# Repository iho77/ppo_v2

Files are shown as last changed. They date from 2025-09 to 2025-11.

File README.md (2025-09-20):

Shield: [][cc-by-nc]

This work is licensed under a
[Creative Commons Attribution-NonCommercial 4.0 International License][cc-by-nc].

[][cc-by-nc]

[cc-by-nc]: https://creativecommons.org/licenses/by-nc/4.0/
[cc-by-nc-image]: https://licensebuttons.net/l/by-nc/4.0/88x31.png
[cc-by-nc-shield]: https://img.shields.io/badge/License-CC%20BY--NC%204.0-lightgrey.svg

# PPO2 Display

A high-precision Partial Pressure of Oxygen (PPO2) monitoring system for technical diving, built on ESP32-C3 with dual O2 sensor support and advanced signal processing algorithms.

## Safety Notes

⚠️ **WARNING**:

OXYGEN PPO MONITORING SOFTWARE

This software is not a dive computer, life-support system, medical device, or safety-critical instrument. It is provided for informational and educational purposes only. Readings may be inaccurate, delayed, or fail due to sensor drift/aging, moisture, calibration error, power or hardware faults, electromagnetic interference, or software bugs.

Do not rely on this software to determine breathing-gas safety. Always follow certified dive training and procedures, use approved equipment, carry independent/redundant instruments, and maintain conservative dive plans. Diving—especially with rebreathers—carries inherent risks of serious injury or death.

The software is provided “AS IS,” without warranties of any kind. To the maximum extent permitted by law, the developer disclaims all liability for any loss, damage, injury, or death arising from use or misuse of this software. By downloading, installing, or using the software, you acknowledge and accept all risks and agree to release, indemnify, and hold the developer harmless from any claims.

If you do not agree, do not use this software.

⚠️ **IMPORTANT**: This sostware developed  using Anthropic Claude heavly with lack of human verification and testing.  

⚠️ **IMPORTANT**: This system is designed for TESTING PURPUSES ONLY. Users must:

1. **Validate Calibration**: Always verify calibration with known gas mixtures
2. **Dual Sensor Monitoring**: Never dive with single sensor operation
3. **Regular Maintenance**: Check sensor health and calibration frequently
4. **Backup Systems**: Always carry independent PPO2 monitoring
5. **Training Required**: Proper technical diving certification essential

This system is a diving aid and should not be the sole method of gas monitoring during technical dives.

## Required Tools & Environment

  - ESP-IDF Framework - Espressif's official development framework
  - CMake (3.16+) - Build system
  - Python - For ESP-IDF tools and flashing
  - Git - For version control and ESP-IDF installation

## Hardware Platform

  - Target MCU: ESP32-C3 Development Board
  - Display: 128x128 SH1107 OLED (I2C at 0x3D, 400kHz)
  - Sensors: Internal ADC for O2 sensor readings
  - Buttons: 2x GPIO buttons (MODE/SELECT)
  - LED: Built-in RGB LED for warnings

## Key Libraries & Components

  - FreeRTOS - Real-time operating system (1kHz tick)
  - ESP-IDF I2C Master Driver - Hardware communication
  - NVS Flash - Non-volatile storage for configuration
  - ESP Task Watchdog - System safety monitoring
  - Custom Components:
    - Display Manager (SH1107 driver)
    - Sensor Manager (O2 sensor interface)
    - Button Manager (GPIO with debouncing)
    - Warning Manager (LED control)
    - PPO2 Logger (data logging)

### Pin Configuration
```
GPIO 0  -> ADC1_CH0 (O2 Sensor 1)
GPIO 1  -> ADC1_CH1 (O2 Sensor 2) 
GPIO 3  -> ADC1_CH3 (Battery voltage divider 1/3)
GPIO 6  -> I2C SDA (Display)
GPIO 7  -> I2C SCL (Display)
GPIO 5  -> MODE Button
GPIO 10  -> SELECT Button
GPIO 8  -> RGB LED (Warning system)
```

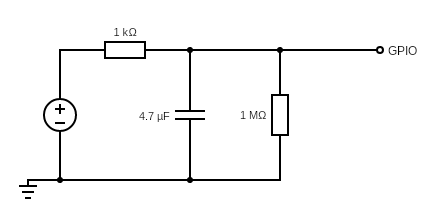
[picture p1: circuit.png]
scheme


## Key Features

### Sensor Management
- **Dual O2 Sensor Support**: Independent sensor processing with disagreement detection
- **Single sensor auto detection**: Short  Sensor + in cable connector to ground - device starts to work in 1 sensor modeI
- **Multipoint Calibration System**: Air (21%), O2 (100%) or custom mix calibration points
- **Advanced Signal Processing**: Median-of-5 → EMA → Slew-rate limiting pipeline
- **Sensor Health Monitoring**: Automatic failure detection and recovery
- **Battery Monitoring**: Real-time voltage and percentage display

### Display System
- **Main Display**: Large PPO2 values with calibration status indicators
- **Warning System**: Scrolling text warnings with LED color coding
- **Battery Display**: Dynamic battery icon with voltage readout
- **Menu System**: Clean navigation with visual selection indicators

### Warning System
- **PPO2 Thresholds**: Configurable low/high warning and alarm levels
- **Sensor Disagreement**: Automatic detection of sensor variance
- **Visual Alerts**: Color-coded LED (Green/Yellow/Red) with blinking patterns
- **Display Integration**: Warning messages shown on main screen

## Core Algorithms

### 1. Robust Signal Processing Pipeline

The system implements a sophisticated 3-stage filtering pipeline for each O2 sensor:

Use 3 stages: spike removal → low-pass → rate limit + debounced alarms.

Spike/outlier killer (median-of-5)
At each 20 Hz step, keep the last 5 raw samples and take the median.

Purpose: remove single-sample glitches without adding much lag (~0.1–0.15 s).

Exponential moving average (EMA) with ~5 s time constant
Let y[n] = y[n−1] + α (x_med[n] − y[n−1]), where x_med is from step 1.

Sampling period dt = 1/20 = 0.05 s.

Choose time constant τ ≈ 5 s → α = dt/τ = 0.05/5 = 0.01.

Why: 5 s LPF kills high-freq jitter while keeping latency modest (~τ behind fast ramps).

Slew-rate limiter (enforce physics)
If the environment cannot change by more than Δ_meaningful per 10 s, set

S_max = Δ_meaningful / 10 (units per second).

Per-sample limit: Δ_per_sample = S_max * dt.
Then clamp the EMA output change:
y_lim[n] = clamp(y[n−1] − Δ_per_sample, y[n], y[n−1] + Δ_per_sample).

Purpose: guarantees your displayed value can’t “move” faster than reality.

Debounced, hysteretic warnings (no flicker)

Trigger threshold: T_hi. Clear threshold: T_lo (with T_lo closer to normal than T_hi → hysteresis gap).

Require persistence: only raise a warning if y_lim[n] > T_hi continuously for T_confirm (e.g., 2–3 s).

Only clear if y_lim[n] < T_lo continuously for T_clear (e.g., 2–3 s).

Implement with two counters that increment while condition holds and reset otherwise.

That stack is O(1) memory and CPU, super stable, and easy to tune.

### 2. Multipoint Calibration System

Replaces traditional linear calibration with a robust 1 or 2-point system:

#### Calibration Points
1. **Air Calibration** (21% O2 at 1 bar): `PPO2 = 0.21 bar`
2. **Oxygen Calibration** (100% O2 at 1 bar): `PPO2 = 1.00 bar`
2. **Custom mix Calibration** (Custom % O2 at 1 bar)

System can works with 1 point calibration or 2 points calibration. In case of 1 point calibration second point is 0 mv\ 0% oxygen.

### 3. Sensor Health Monitoring

#### Health Checks
1. **Voltage Range Validation**: 0-1000mV acceptable range
2. **Calibration Validity**: Both sensors must have valid calibration
3. **Sensor Disagreement**: PPO2 difference > 0.05 bar triggers warning
4. **Communication Errors**: ADC read failures tracked and recovered

# Calibration-Based Drift & Linearity Tracking (Strategy 1)

A clear, hands-on guide you can mirror in logs, a spreadsheet, or firmware notes.

## What you track (per sensor)

* **Gain / sensitivity `k`** (mV/ata): millivolts per 1.0 ata ppO₂.
* **Offset `b`** (mV): reading at ppO₂ = 0 (should be near 0).
* **Normalized sensitivity `S = k / k₀`** vs **new-sensor baseline** `k₀`.
* **Linearity** across multiple known ppO₂ points: **`R²`** and **max residual** (mV).
* **Drift rate** (e.g., %/month) and **predicted EOL** date (when `S` hits your fail threshold, e.g., `0.70`).

---

## Two-Point Calibration (minimum viable)

At each calibration, expose the sensor to two **known** ppO₂ points and record:

* `(p₁, m₁)`: e.g., **air at surface** → `p₁ ≈ 0.209` ata, measured `m₁` (mV)
* `(p₂, m₂)`: e.g., **100% O₂ at surface** → `p₂ = 1.00` ata, measured `m₂` (mV)

Fit a line `m = k·p + b`:

```
k = (m₂ − m₁) / (p₂ − p₁)
b = m₁ − k · p₁
```

Then compute **normalized sensitivity**:

```
S = k / k₀
```

Where `k₀` is your **new-sensor baseline** (mV/ata).

---

## Worked Example A — two-point checks over time (one sensor)

Assume `k₀ = 52.0` mV/ata (≈ 11 mV in air, ≈ 52 mV at 1.0 ata O₂).

| Date | Air mV `m₁` | O₂ mV `m₂` | Estimated `k` (mV/ata) | `b` (mV) | `S = k/k₀` |
| --- | ---: | ---: | ---: | ---: | ---: |
| 2025-01-01 | 10.99 | 52.25 | 52.16 | 0.09 | 1.003 |
| 2025-05-01 | 10.45 | 49.51 | 49.37 | 0.14 | 0.950 |
| 2025-10-01 | 9.48 | 45.86 | 46.00 | −0.14 | 0.885 |
| 2026-03-01 | 8.18 | 39.82 | 39.99 | −0.18 | 0.769 |

### Interpretation

* Sensitivity `S` drifts from \~1.00 → 0.77 over \~14 months (≈ 1.6 %/month).
* **Caution** when `S < 0.80` (here: 2026-03-01).
* **Predict EOL** when `S` hits **0.70**: extrapolation from the last trend ≈ **Aug 2026** (\~19 months from first calibration).

**Log each time:** the two mV readings and the computed `k`, `b`, `S`, plus a trendline of `S` vs time (and ETA to `S = 0.70`).

---

## Practical guardrails

* If `|b| > 2–3` mV or it drifts steadily, investigate (zero-current leakage, moisture, wiring).
* If degradation accelerates (> \~3–5 %/month), plan an early swap.

#### Failure Recovery
- **Graceful Degradation**: System continues with single sensor
- **Fail-Safe PPO2**: Conservative 0.21 bar default during total failure
- **Automatic Recovery**: Sensors re-validated on successful reads

### 4. Warning State Machine

#### Warning States
```c
typedef enum {
    WARNING_STATE_NORMAL = 0,    // Green LED - PPO2 in range
    WARNING_STATE_WARNING,       // Yellow blinking - PPO2 at limits  
    WARNING_STATE_ALARM         // Red blinking - PPO2 dangerous
} warning_state_t;
```

#### PPO2 Thresholds (Configurable)
- **Low Warning**: 0.19 bar (hypoxia risk)
- **Low Alarm**: 0.18 bar (severe hypoxia)
- **High Warning**: 1.4 bar (oxygen toxicity risk)
- **High Alarm**: 1.6 bar (severe toxicity risk)

#### LED Patterns
- **Normal**: Solid green
- **Warning**: Yellow blink at 2Hz (250ms on/off)
- **Alarm**: Red blink at 4Hz (125ms on/off)

## System Architecture

### Component Organization
```
├── main/                   # Main application and mode management
│   ├── main.c             # System initialization and 20Hz main loop
│   └── modes/             # Mode-specific implementations
├── components/
│   ├── app_common/        # Shared types and configuration
│   ├── sensor_manager/    # O2 sensor processing and calibration
│   ├── display_manager/   # LVGL display driver and UI
│   ├── warning_manager/   # LED warning system
│   ├── button_manager/    # GPIO button handling
│   └── sh1107_driver/     # Low-level display driver
```

### Data Flow
```
Sensors (20Hz) → Filtering → Calibration → Warning Analysis → Display Update
                     ↓
              Health Monitoring → Recovery Actions
```

## Menu System

### Main Menu Items
1. **Sensor Calibration** - Dual sensor calibration with gas selection
2. **Reset Calibration** - Individual or bulk calibration reset
3. **Print Logs** - Debug output to serial console
4. **Sensor Health** - Real-time sensor diagnostics
5. **System Setup** - Configuration and thresholds
6. **Power Off** - System shutdown

### Calibration Workflow
1. **Gas Selection**: Air, O2, or Custom (configurable %)
2. **Dual Sensor Display**: Live mV readings for both sensors
3. **Calibration Action**: Simultaneous calibration of both sensors
4. **Validation**: Automatic sanity checks and confirmation

### Setup Options
- **PPO2 Thresholds**: Warning and alarm levels for low/high PPO2
- **Display Settings**: Brightness and contrast
- **Sensor Configuration**: Individual sensor enable/disable
- **System Parameters**: Sample rates and filter constants

## Technical Specifications

### Performance
- **Update Rate**: 20 Hz sensor sampling and display refresh
- **Response Time**: ~5 seconds (90% settling due to EMA filtering)
- **Accuracy**: ±0.01 bar PPO2 (post-calibration)
- **Resolution**: 12-bit ADC (0.25mV resolution)

## Contributing

Contributions welcome! Please read CONTRIBUTING.md for guidelines on:
- Code style and standards
- Testing requirements
- Safety considerations for diving equipment

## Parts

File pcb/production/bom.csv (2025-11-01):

Designator | Footprint | Quantity | Value | LCSC Part #
BT1 | JST_XH_B2B-XH-A_1x02_P2.50mm_Vertical | 1 | Battery | C7429632
C1, C2 | 0805 | 2 | 1uF | C24123
C3 | 0805 | 1 | 4.7uF | C107365
C4, C5 | 0805 | 2 | 10uF | C1713
J1, J2 | JST_XH_B2B-XH-A_1x02_P2.50mm_Vertical | 2 | Conn_01x02_Socket | C7429632
J3 | JST_XH_B4B-XH-AM_1x04_P2.50mm_Vertical | 1 | Conn_01x04_Socket
L1 | 0402 | 1 | 1.5uH | C6364721
R1, R2 | 0805 | 2 | 10K | C17414
R3 | 0805 | 1 | 200k | C149504
R4 | 0805 | 1 | 100K | C2907238
U3 | WSON-10-1EP_2.5x2.5mm_P0.5mm_EP1.2x2mm | 1 | TPS63031DSK | C15516

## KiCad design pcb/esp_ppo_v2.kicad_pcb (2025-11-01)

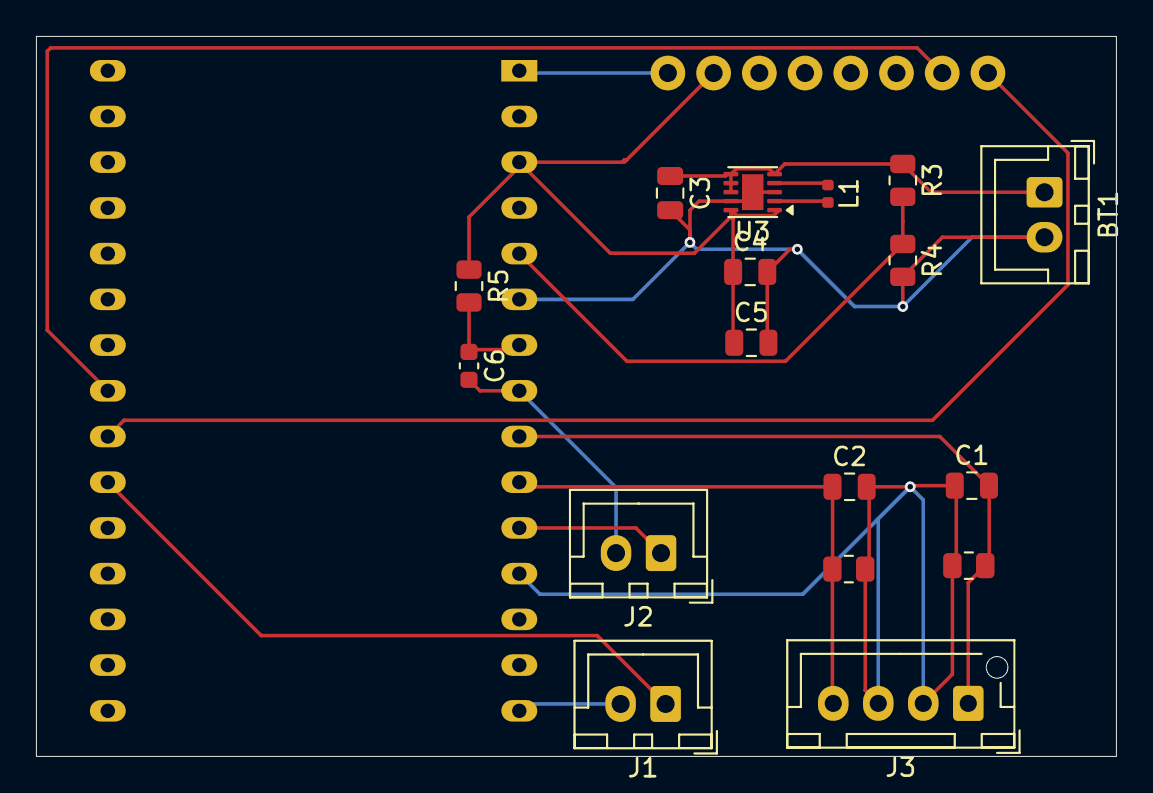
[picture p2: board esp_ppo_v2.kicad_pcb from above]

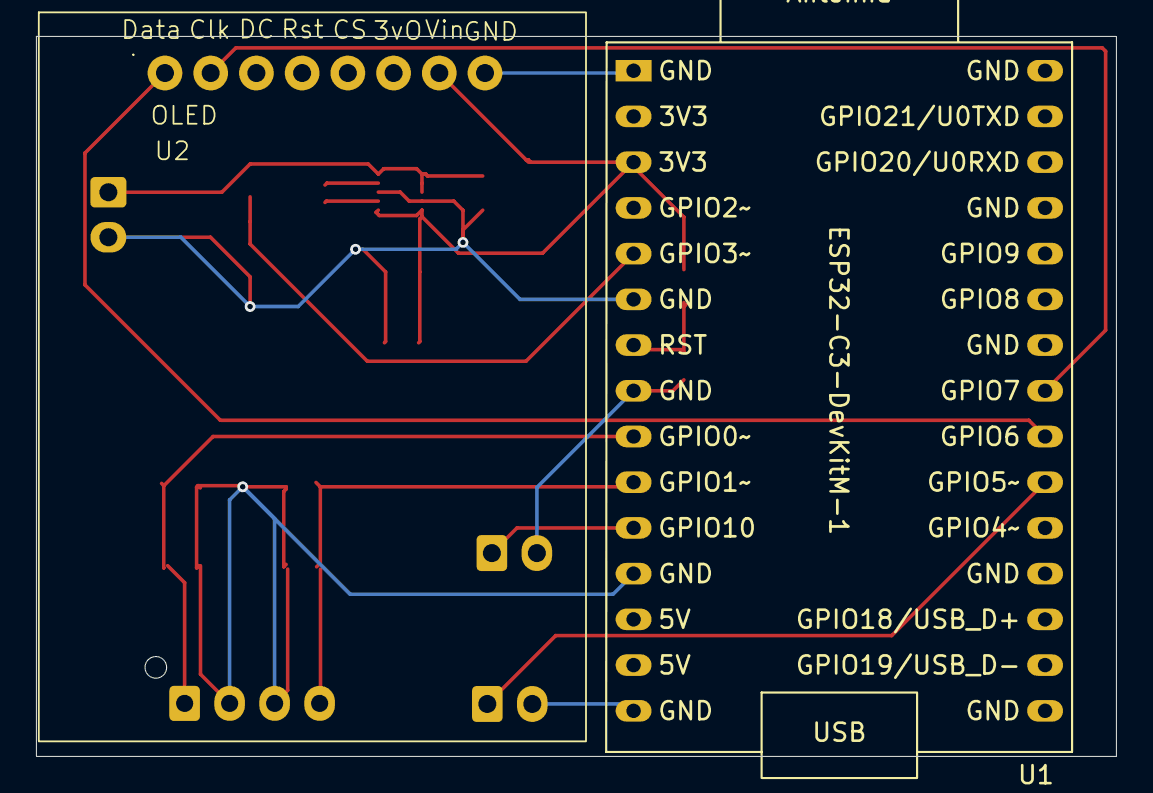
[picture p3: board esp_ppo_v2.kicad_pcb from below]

Board: 2 copper layers, 60.0 x 40.0 mm, 19 parts (2 on the bottom side), 13 nets.

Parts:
BT1: Battery; JST_XH_B2B-XH-A_1x02_P2.50mm_Vertical
C1, C2: 1uF; C_0805_2012Metric
C3: 4.7uF; C_0805_2012Metric
C4, C5: 10uF; C_0805_2012Metric
C6: 10uF; C_0603_1608Metric
J1, J2: Conn_01x02_Socket; JST_XH_B2B-XH-A_1x02_P2.50mm_Vertical
J3: Conn_01x04_Socket; JST_XH_B4B-XH-AM_1x04_P2.50mm_Vertical
L1: 1.5uH; L_0402_1005Metric
R1, R2: 10K; R_0805_2012Metric
R3: 200k; R_0805_2012Metric
R4: 100K; R_0805_2012Metric
R5: 10k; R_0805_2012Metric
U1: ESP32-C3-DevKitM-1
U2: 128x128_OLED
U3: TPS63031DSK; WSON-10-1EP_2.5x2.5mm_P0.5mm_EP1.2x2mm

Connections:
+3.3V: C4.1, C5.1, R5.1, U1.2 (3V3), U1.3 (3V3), U2.7 (Vin), U3.1 (VOUT), U3.10 (FB)
+BATT: BT1.1 (+), C3.1, R3.1, U3.5 (VIN), U3.6 (EN), U3.7 (PS/SYNC), U3.8 (VINA)
ADC_1: C2.1, J3.4, R2.1, U1.10 (GPIO1)
ADC_2: C1.2, J3.1, R1.2, U1.9 (GPIO0)
ADC_BAT: R3.2, R4.1, U1.5 (GPIO3)
BTN-M: J1.1, U1.21 (GPIO5)
BTN-S: J2.1, U1.11 (GPIO10)
GND: BT1.2 (-), C1.1, C2.2, C3.2, C4.2, C5.2, C6.2, J1.2, J2.2, J3.2, J3.3, R1.1, R2.2, R4.2, U1.1 (GND), U1.6 (GND), U1.8 (GND), U1.12 (GND), U1.15 (GND), U1.16 (GND), U1.19 (GND), U1.24 (GND), U1.27 (GND), U1.30 (GND), U2.8 (GND), U3.3 (PGND), U3.9 (GND), U3.11 (PGND)
unnamed: C6.1, R5.2, U1.7 (RST)
unnamed: L1.1, U3.4 (L1)
unnamed: L1.2, U3.2 (L2)
SCL: U1.23 (GPIO7), U2.2 (Clk)
SDA: U1.22 (GPIO6), U2.1 (Data)

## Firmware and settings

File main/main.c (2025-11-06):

/**
 * @file main.c
 * @brief PPO2 HUD main application - Simplified architecture
 */

#include "sdkconfig.h"
#include "freertos/FreeRTOS.h"
#include "freertos/task.h"
#include "esp_system.h"
#include "esp_log.h"
#include "esp_timer.h"
#include "nvs_flash.h"
#include <math.h>
#include <string.h>

// Application components
#include "button_manager.h"
#include "display_manager.h"
#include "sensor_manager.h"
#include "sensor_calibration.h"  // For sensor health enums
#include "ppo2_logger.h"          // PPO2 measurement logging
// Using internal ADC and no external sensor managers
#include "warning_manager.h"
#include "app_types.h"
#include "app_config.h"
#include "driver/i2c_master.h"
#include "esp_sleep.h"
#include "driver/gpio.h"
#include "driver/rtc_io.h"
#include "soc/rtc.h"
#include "esp_task_wdt.h"
#include "driver/usb_serial_jtag.h"

static const char *TAG = "PPO2_HUD";

// ========== HARDWARE CONFIGURATION ==========
// GPIO Pin Assignments for ESP32-C3 Development Board
#define GPIO_I2C_SDA            GPIO_NUM_6  // I2C Data line blue
#define GPIO_I2C_SCL            GPIO_NUM_7  // I2C Clock line  yellow
#define GPIO_BUTTON_MODE        GPIO_NUM_10  // Mode/menu button
#define GPIO_BUTTON_SELECT      GPIO_NUM_5  // Select/enter button
#define GPIO_WARNING_LED        GPIO_NUM_8  // Built-in RGB LED
//#define GPIO_WARNING_1LED       GPIO_NUM_12  // Not used
//#define GPIO_WARNING_2LED       GPIO_NUM_13  // Not used

// I2C bus configuration
#define I2C_BUS_SDA_PIN         GPIO_I2C_SDA
#define I2C_BUS_SCL_PIN         GPIO_I2C_SCL
#define I2C_BUS_FREQ_HZ         100000
#define I2C_BUS_PORT            I2C_NUM_0

// I2C Device addresses
// Display I2C address is handled by display_manager (uses 0x3D default for SH1107)
// Using internal ADC - no external I2C sensor addresses needed

// Warning system configuration
#define WARNING_LED_GPIO        GPIO_WARNING_LED

// Application states (simplified from complex mode system)
typedef enum {
    APP_STATE_MAIN = 0,        // Primary diving display
    APP_STATE_MENU,            // Menu overlay
    APP_STATE_CALIBRATION,     // Calibration overlay
    APP_STATE_CAL_RESET,       // Calibration reset screen
    APP_STATE_SETUP,           // Setup overlay
    APP_STATE_LOG,             // Log viewer overlay  
    APP_STATE_PRINT_CALIBRATION, // Print calibration to debug and show message
    APP_STATE_SENSOR_HEALTH,   // Print sensor health to debug and show message
    APP_STATE_SYSTEM_MESSAGE,  // System message display
    APP_STATE_MAX
} app_state_t;

// Setup mode menu items
typedef enum {
    SETUP_ITEM_WARN_LOW_PPO2 = 0,
    SETUP_ITEM_ALARM_LOW_PPO2,
    SETUP_ITEM_WARN_HIGH_PPO2,
    SETUP_ITEM_ALARM_HIGH_PPO2,
    SETUP_ITEM_SENSOR_DISAGREEMENT,
    SETUP_ITEM_ATMOSPHERIC_PRESSURE,
    SETUP_ITEM_SAVE,
    SETUP_ITEM_BACK,
    SETUP_ITEM_COUNT
} setup_item_t;

// Display update thresholds
#define PPO2_DISPLAY_UPDATE_THRESHOLD 0.02f  // Update display if PPO2 changes by >= 0.02
#define DISPLAY_MAX_STALENESS_MS      1000   // Always refresh at least once per second



// Application context
typedef struct {
    app_state_t current_state;
    app_state_t previous_state;
    uint32_t state_entry_time;
    uint8_t menu_selected_item;
    uint8_t menu_item_count;
    // Calibration mode state (dual sensor simultaneous calibration)
    float calibration_o2_percent;  // Known O2 percentage for calibration
    uint8_t calibration_menu_item;  // Current menu item being navigated
    uint8_t calibration_selected_gas; // Selected gas type for calibration (1=Air, 2=O2, 3=Custom)
    bool calibration_custom_editing; // True when editing custom percentage
    bool calibration_in_action_mode; // True when navigating calibrate/back, false when selecting gas
    bool calibration_session_active; // True if first gas has been calibrated, waiting for second gas
    float calibration_first_gas_percent; // O2 percentage of first calibrated gas
    // Setup mode state
    uint8_t setup_selected_item;   // Current setup menu item
    bool setup_editing;            // True when editing a value
    uint8_t setup_digit_index;     // Current digit being edited (0-based)
    uint8_t setup_digit_count;     // Total number of digits for current value
    app_config_t setup_temp_config; // Temporary config for editing
    // Calibration reset mode state
    uint8_t cal_reset_menu_item;   // 0=reset live, 1=reset default, 2=back
    float current_sensor0_mv;      // Current sensor 0 reading (mV)
    float current_sensor1_mv;      // Current sensor 1 reading (mV)
    // System message state
    char system_message[256];      // Current system message text
} app_context_t;

// Global application context
static app_context_t s_app_ctx = {
    .current_state = APP_STATE_MAIN,
    .previous_state = APP_STATE_MAIN,
    .menu_selected_item = 0,
    .menu_item_count = 6, // Will be updated dynamically in app_main()
    .calibration_o2_percent = O2_PERCENT_DEFAULT_AIR,
    .calibration_menu_item = 1,
    .calibration_selected_gas = 1, // Start with Air selected
    .calibration_custom_editing = false,
    .calibration_in_action_mode = false, // Start in gas selection mode
    .calibration_session_active = false,
    .calibration_first_gas_percent = 0.0f,
    .setup_selected_item = 0,
    .setup_editing = false,
    .setup_digit_index = 0,
    .setup_digit_count = 0,
    .cal_reset_menu_item = 0,
    .current_sensor0_mv = 0.0f,
    .current_sensor1_mv = 0.0f,
    .system_message = ""
};

// Global I2C bus handle for display (new driver)
static i2c_master_bus_handle_t s_i2c_bus = NULL;

// Application runtime state (simplified) with watchdog
static struct {
    uint32_t runtime_seconds;
    uint32_t last_update_time;
    uint32_t last_successful_sensor_read;
    uint32_t sensor_recovery_attempts;
    bool in_recovery_mode;
} s_runtime_state = {
    .runtime_seconds = 0,
    .last_update_time = 0,
    .last_successful_sensor_read = 0,
    .sensor_recovery_attempts = 0,
    .in_recovery_mode = false
};

// Display change-detection cache
static struct {
    bool initialized;
    float last_s1_ppo2;
    float last_s2_ppo2;
    char last_cal_status_s1[8];
    char last_cal_status_s2[8];
    bool state_changed; // force redraw on state transitions
    uint32_t last_ui_update_ms;
    bool last_battery_low;
    bool last_valid;
    sensor_failure_t last_failure_type;
} s_display_cache = {
    .initialized = false,
    .last_s1_ppo2 = 0.0f,
    .last_s2_ppo2 = 0.0f,
    .last_cal_status_s1 = "",
    .last_cal_status_s2 = "",
    .state_changed = false,
    .last_ui_update_ms = 0,
    .last_battery_low = false,
    .last_valid = true,
    .last_failure_type = SENSOR_FAIL_NONE
};

// Menu items - updated to match new UI architecture
static const menu_item_t s_menu_items[] = {
    {"sensor calibration", MODE_CALIBRATION},
    {"reset calibration", MODE_CAL_RESET},
    {"print logs", MODE_LOG},
    {"sensor health", MODE_SENSOR_HEALTH},
    {"setup", MODE_SETUP},
    {"power off", MODE_SLEEP},
    {"back", MODE_MAIN}
};

// Function declarations
static esp_err_t init_i2c_bus(void);
static esp_err_t probe_i2c_health(void);
static void handle_button_events(void);
static void update_runtime_state(void);
static void update_display(void);
static void show_main_display(void);
static void show_menu_overlay(void);
static void show_calibration_overlay(void);
static void show_calibration_reset_overlay(void);
static void show_setup_overlay(void);
static void show_print_calibration_overlay(void);
static void show_sensor_health_overlay(void);
static void show_system_message_overlay(void);
static void enter_state(app_state_t new_state);
static const char* state_to_string(app_state_t state);
static void calibration_increment_custom_o2(void);
static void calibration_perform_with_o2(float o2_percent);
static void setup_increment_digit(void);
static void setup_save_config(void);
static void setup_get_digit_info(uint8_t item, uint8_t *digit_count);
static void format_ppo2_item(display_data_t *display_data, const char *title, float value);
static void increment_ppo2_digit(float *value);
static void perform_calibration_reset_all(void);
static void perform_calibration_reset_sensor_0(void);
static void perform_calibration_reset_sensor_1(void);
static void update_calibration_reset_readings(void);
static void attempt_sensor_recovery(void);
static void check_system_watchdog(void);
static void enter_deep_sleep_mode(void);


static void i2c_bus_recover(gpio_num_t sda, gpio_num_t scl) {
    // Release pins from I2C driver (if installed, uninstall first)
    gpio_reset_pin(sda);
    gpio_reset_pin(scl);

    // SDA input (floating), SCL open-drain output held high
    gpio_set_direction(sda, GPIO_MODE_INPUT);
    gpio_set_pull_mode(sda, GPIO_FLOATING);

    gpio_set_direction(scl, GPIO_MODE_OUTPUT_OD);
    gpio_set_level(scl, 1);
    esp_rom_delay_us(5);

    // 9 clock pulses to free a stuck slave
    for (int i = 0; i < 9; i++) {
        gpio_set_level(scl, 0); esp_rom_delay_us(5);
        gpio_set_level(scl, 1); esp_rom_delay_us(5);
        if (gpio_get_level(sda)) break;
    }

    // Generate a STOP (SDA low -> SCL high -> SDA high)
    gpio_set_direction(sda, GPIO_MODE_OUTPUT_OD);
    gpio_set_level(sda, 0);    esp_rom_delay_us(5);
    gpio_set_level(scl, 1);    esp_rom_delay_us(5);
    gpio_set_level(sda, 1);    esp_rom_delay_us(5);
}



void app_main(void)
{
    // Check wake-up cause and force reinitialization if waking from deep sleep
    esp_sleep_wakeup_cause_t wakeup_reason = esp_sleep_get_wakeup_cause();
    switch (wakeup_reason) {
        case ESP_SLEEP_WAKEUP_GPIO: {
            uint64_t wakeup_pin_mask = esp_sleep_get_gpio_wakeup_status();
            if (wakeup_pin_mask != 0) {
                int pin = __builtin_ffsll(wakeup_pin_mask) - 1;
                ESP_LOGI(TAG, "Wake-up caused by GPIO %d - forcing manager reinitialization", pin);
            } else {
                ESP_LOGI(TAG, "Wake-up caused by GPIO - forcing manager reinitialization");
            }
            
            // Force reinitialization of managers after deep sleep
            // Static variables retain their values, but hardware state is reset
            ESP_LOGI(TAG, "Deinitializing managers to force clean reinitialization");
            display_manager_deinit();
            sensor_manager_deinit();
            break;
        }
        case ESP_SLEEP_WAKEUP_UNDEFINED:
        default:
            ESP_LOGI(TAG, "Wake-up not caused by deep sleep (normal boot)");
            break;
    }
    
    // Set global log level to DEBUG for detailed sensor calibration logs
    esp_log_level_set("*", ESP_LOG_ERROR);

    ESP_LOGI(TAG, "Starting PPO2 HUD application (Simplified Architecture)");
    ESP_LOGI(TAG, "ESP-IDF Version: %s", esp_get_idf_version());
    ESP_LOGI(TAG, "Free heap: %d bytes", esp_get_free_heap_size());

    // Initialize NVS
    esp_err_t ret = nvs_flash_init();
    if (ret == ESP_ERR_NVS_NO_FREE_PAGES || ret == ESP_ERR_NVS_NEW_VERSION_FOUND) {
        ESP_ERROR_CHECK(nvs_flash_erase());
        ret = nvs_flash_init();
    }
    ESP_ERROR_CHECK(ret);

    

    

    // Using internal ADC for O2 sensors - no external sensor initialization needed

    // Initialize core components
    ESP_LOGI(TAG, "Initializing components...");
    
    esp_err_t app_config_ret = app_config_init();
    if (app_config_ret != ESP_OK) {
        ESP_LOGE(TAG, "Failed to initialize app config: %s", esp_err_to_name(app_config_ret));
    }
    
    esp_err_t sensor_mgr_ret = sensor_manager_init();
    if (sensor_mgr_ret != ESP_OK) {
        app_log_error_to_display(TAG, "Failed to initialize sensor manager: %s", esp_err_to_name(sensor_mgr_ret));
    } else {
        ESP_LOGI(TAG, "Sensor manager initialized successfully");
    }
    
    // Initialize PPO2 logger (depends on sensor manager)
    esp_err_t ppo2_logger_ret = ppo2_logger_init();
    if (ppo2_logger_ret != ESP_OK) {
        ESP_LOGW(TAG, "Failed to initialize PPO2 logger: %s", esp_err_to_name(ppo2_logger_ret));
    } else {
        ESP_LOGI(TAG, "PPO2 logger initialized successfully");
    }
    
    // Check if sensor manager can read data (for informational purposes only)
    sensor_data_t test_data;
    esp_err_t sensor_test = sensor_manager_read(&test_data);
    if (sensor_test != ESP_OK || !test_data.valid) {
        if (test_data.failure_type == SENSOR_FAIL_CALIBRATION_INVALID) {
            ESP_LOGW(TAG, "No valid calibrations found - user must reset calibrations through menu");
        } else {
            ESP_LOGW(TAG, "Sensor readings failed - sensors may not be connected");
        }
    } else {
        ESP_LOGI(TAG, "Sensor readings successful, calibrations valid");
    }
    
   
    // Initialize button manager with GPIO configuration
    button_config_t button_config = {
        .mode_gpio = GPIO_BUTTON_MODE,
        .select_gpio = GPIO_BUTTON_SELECT
    };
    ESP_ERROR_CHECK_WITHOUT_ABORT(button_manager_init(&button_config));

    // Initialize warning manager with built-in LED
    ESP_LOGI(TAG, "Initializing warning manager...");
    warning_config_t warning_config = {
        .led_gpio = WARNING_LED_GPIO,
        .use_led_strip = true  // ESP32-C3 has addressable LED
    };
    ESP_ERROR_CHECK_WITHOUT_ABORT(warning_manager_init(&warning_config));

    // === OPTION 7: STAGED DISPLAY INITIALIZATION WITH COMPREHENSIVE RETRY ===
    ESP_LOGI(TAG, "=== Starting Comprehensive Display Initialization ===");
   // === OPTION 1: Staged Power-Up with I2C Bus Conditioning ===
    // Extended delay to allow battery voltage to stabilize (especially with fresh CR2)
    ESP_LOGI(TAG, "Waiting for power stabilization (2.5s)...");
    vTaskDelay(pdMS_TO_TICKS(2500));

    // First I2C bus recovery attempt
    ESP_LOGI(TAG, "Performing first I2C bus recovery...");
    i2c_bus_recover(I2C_BUS_SDA_PIN, I2C_BUS_SCL_PIN);
    vTaskDelay(pdMS_TO_TICKS(200));  // Allow bus to settle

    // Second I2C bus recovery attempt for reliability
    ESP_LOGI(TAG, "Performing second I2C bus recovery...");
    i2c_bus_recover(I2C_BUS_SDA_PIN, I2C_BUS_SCL_PIN);
    vTaskDelay(pdMS_TO_TICKS(200));  // Allow bus to settle

    // Initialize I2C systems
    ESP_LOGI(TAG, "Initializing I2C systems...");
    ESP_ERROR_CHECK_WITHOUT_ABORT(init_i2c_bus());  // For both display and ADS1115 (new driver)

    // Allow I2C bus to stabilize after initialization
    vTaskDelay(pdMS_TO_TICKS(100));

    // Probe I2C bus health before display initialization
    ESP_LOGI(TAG, "Performing multi-stage I2C health check...");
    probe_i2c_health();
    vTaskDelay(pdMS_TO_TICKS(100));  // Small delay after probe

    // Initialize display manager with new I2C master driver
    display_config_t display_config = {
        .i2c_bus = s_i2c_bus,
        .i2c_address = 0,  // Use display manager's default (0x3D for SH1107)
        .i2c_freq_hz = I2C_BUS_FREQ_HZ
    };

    esp_err_t disp_ret = ESP_FAIL;
    const int max_attempts = 3;
    const uint32_t retry_delays_ms[] = {500, 1000, 2000};  // Exponential backoff

    for (int attempt = 0; attempt < max_attempts; attempt++) {
        ESP_LOGI(TAG, "Display initialization attempt %d/%d...", attempt + 1, max_attempts);

        disp_ret = display_manager_init(&display_config);

        if (disp_ret == ESP_OK) {
            ESP_LOGI(TAG, "Display initialization SUCCESS on attempt %d", attempt + 1);
            break;
        }

        ESP_LOGE(TAG, "Display initialization FAILED on attempt %d: %s",
                 attempt + 1, esp_err_to_name(disp_ret));

        // If not last attempt, perform recovery and retry
        if (attempt < max_attempts - 1) {
            uint32_t delay_ms = retry_delays_ms[attempt];
            ESP_LOGI(TAG, "Performing recovery procedure before retry (delay: %lums)...", delay_ms);

            // Deinitialize display manager to reset state
            display_manager_deinit();
            vTaskDelay(pdMS_TO_TICKS(200));

            // Perform additional I2C bus recovery
            ESP_LOGI(TAG, "Additional I2C bus recovery...");
            i2c_bus_recover(I2C_BUS_SDA_PIN, I2C_BUS_SCL_PIN);
            vTaskDelay(pdMS_TO_TICKS(200));

            // Wait with exponential backoff
            ESP_LOGI(TAG, "Waiting %lums for power/bus stabilization...", delay_ms);
            vTaskDelay(pdMS_TO_TICKS(delay_ms));

            // Probe health again before retry
            ESP_LOGI(TAG, "Re-probing I2C health before retry...");
            probe_i2c_health();
            vTaskDelay(pdMS_TO_TICKS(100));
        }
    }

    if (disp_ret != ESP_OK) {
        ESP_LOGE(TAG, "Display initialization FAILED after %d attempts", max_attempts);
        ESP_LOGE(TAG, "System may not be usable - check hardware connections");
        ESP_ERROR_CHECK_WITHOUT_ABORT(disp_ret);
    }

    // Additional settling delay after successful display initialization
    ESP_LOGI(TAG, "Final display stabilization delay (300ms)...");
    vTaskDelay(pdMS_TO_TICKS(300));

    ESP_LOGI(TAG, "All components initialized successfully");

    // Start PPO2 logger after all components are ready
    if (ppo2_logger_ret == ESP_OK) {
        esp_err_t start_ret = ppo2_logger_start();
        if (start_ret != ESP_OK) {
            ESP_LOGW(TAG, "Failed to start PPO2 logger: %s", esp_err_to_name(start_ret));
        } else {
            ESP_LOGI(TAG, "PPO2 logger started - logging every minute");
        }
    }

    // Add current task to existing watchdog for safety monitoring
    esp_err_t wdt_ret = esp_task_wdt_add(NULL);  // Add current task to existing watchdog
    if (wdt_ret == ESP_OK) {
        ESP_LOGI(TAG, "Main task added to hardware watchdog");
    } else {
        ESP_LOGW(TAG, "Failed to add task to watchdog: %s", esp_err_to_name(wdt_ret));
    }

    // Display startup message
    display_data_t startup_msg = {0};
    startup_msg.mode = DISPLAY_MODE_TEXT;
    snprintf(startup_msg.line1, sizeof(startup_msg.line1), "HUD v2.0");
    snprintf(startup_msg.line2, sizeof(startup_msg.line2), "2025");
    snprintf(startup_msg.line3, sizeof(startup_msg.line3), "Starting...");
    display_manager_update_system_message("Starting....");
  //  display_manager_update(&startup_msg);
//    display_manager_update_system_message   (&startup_msg);
    
    vTaskDelay(pdMS_TO_TICKS(3000));

    // Initialize application state
    s_app_ctx.current_state = APP_STATE_MAIN;
    s_app_ctx.state_entry_time = esp_timer_get_time() / 1000;
    s_app_ctx.menu_item_count = sizeof(s_menu_items) / sizeof(s_menu_items[0]);

    ESP_LOGI(TAG, "Starting main application loop in %s state", state_to_string(s_app_ctx.current_state));

    // Initialize recovery state
    s_runtime_state.last_successful_sensor_read = esp_timer_get_time() / 1000;
    
    // Main application loop with enhanced safety monitoring
    uint32_t loop_count = 0;
    const TickType_t loop_period = pdMS_TO_TICKS(SYSTEM_MAIN_LOOP_DELAY_MS);
    TickType_t last_wake = xTaskGetTickCount();
    while (1) {
        // Feed watchdog to prevent system reset
        esp_task_wdt_reset();
        
        // Update hardware (always active)
        button_manager_update();
        sensor_manager_update();
        
        // Update warning system based on latest sensor data
        sensor_data_t sensor_data;
        esp_err_t sensor_ret = sensor_manager_read(&sensor_data);
        if (sensor_ret == ESP_OK && sensor_data.valid) {
            s_runtime_state.last_successful_sensor_read = esp_timer_get_time() / 1000;
            s_runtime_state.in_recovery_mode = false;
            ESP_LOGD(TAG, "Sensor read successful: S1 PPO2=%3ld, S2 PPO2=%3ld", 
                     sensor_data.o2_sensor1_ppo2_mbar, sensor_data.o2_sensor2_ppo2_mbar);
            warning_manager_update(&sensor_data);
        } else {
            // Sensor read failed or data invalid - check for recovery
            check_system_watchdog();
        }
        
        bool on_usb;

        if(sensor_data.battery_voltage_mv <= 2500) {
            on_usb = true;
        } else {
            on_usb = false;
        } ; //for debug over pc

       
        if (sensor_data.battery_percentage == 0 && !on_usb) {
            ESP_LOGE(TAG, "Battery critically low - entering deep sleep"); 
            enter_deep_sleep_mode();
        }

        // Handle button events
        handle_button_events();
        
        // Update runtime state (simplified)
        update_runtime_state();
        
        // Update display based on current state
        update_display();
        
        // Periodic logging and health checks
        if ((++loop_count % SYSTEM_STATUS_LOG_INTERVAL) == 0) {  // Every 10 seconds at 20Hz
            ESP_LOGI(TAG, "Loop #%lu in %s state, heap: %d bytes, recovery: %s", 
                     loop_count, state_to_string(s_app_ctx.current_state), 
                     esp_get_free_heap_size(), s_runtime_state.in_recovery_mode ? "YES" : "NO");
                     
            // Check for memory leaks
            if (esp_get_free_heap_size() < SYSTEM_HEAP_WARNING_THRESHOLD) {  // Memory warning threshold
                ESP_LOGW(TAG, "Low memory warning: %d bytes free", esp_get_free_heap_size());
            }
        }
        
        vTaskDelayUntil(&last_wake, loop_period);  // 20Hz update rate, no drift
    }

    // Cleanup (never reached)
    ESP_LOGI(TAG, "Shutting down application");
    sensor_manager_deinit();
    // No external sensor managers to deinitialize
    warning_manager_deinit();
    display_manager_deinit();
    button_manager_deinit();
    
    // Cleanup I2C systems
    if (s_i2c_bus) {
        i2c_del_master_bus(s_i2c_bus);
        s_i2c_bus = NULL;
    }
}
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

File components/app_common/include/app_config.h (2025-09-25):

/**
 * @file app_config.h
 * @brief Configuration constants for ESP32-C3 sensor monitoring system
 */

#ifndef APP_CONFIG_H
#define APP_CONFIG_H

#include "app_types.h"
#include "esp_err.h"

// Hardware pin definitions (moved to component-specific files)
// GPIO assignments are now defined where they are actually used

// Only keep constants that are actually used across multiple components
// Component-specific constants have been moved to their respective files

// Communication timeouts (used by multiple I2C components)
#define I2C_TIMEOUT_MS              500

// PPO2 alarm and warning default limits (bar)
#define PPO2_DEFAULT_LOW_WARNING    180  // Low PPO2 warning at 0.16 bar
#define PPO2_DEFAULT_LOW_ALARM      170  // Low PPO2 alarm at 0.10 bar
#define PPO2_DEFAULT_HIGH_WARNING   1450  // High PPO2 warning at 1.40 bar
#define PPO2_DEFAULT_HIGH_ALARM     1600  // High PPO2 alarm at 1.60 bar

// Sensor monitoring defaults
#define SENSOR_DEFAULT_DISAGREEMENT_THRESHOLD 0.05f  // 0.05 bar difference threshold
#define ATMOSPHERIC_DEFAULT_PRESSURE          1.013f // Standard atmospheric pressure (bar)

// Display default settings
#define DISPLAY_DEFAULT_BRIGHTNESS  80     // 80% brightness
#define DISPLAY_DEFAULT_CONTRAST    50     // 50% contrast
#define DISPLAY_DEFAULT_AUTO_BRIGHT true   // Auto brightness enabled

// System default settings
#define SYSTEM_DEFAULT_SLEEP_TIMEOUT_S  300  // 5 minutes sleep timeout

// Legacy O2 calibration constants removed - using simplified calibration system

// NVS namespace and keys
#define NVS_NAMESPACE_CONFIG        "config"

// PPO2 limit keys
#define NVS_KEY_PPO2_LOW_WARN       "ppo2_low_warn"
#define NVS_KEY_PPO2_LOW_ALARM      "ppo2_low_alarm"
#define NVS_KEY_PPO2_HIGH_WARN      "ppo2_high_warn"
#define NVS_KEY_PPO2_HIGH_ALARM     "ppo2_hi_alarm"

// Sensor monitoring keys
#define NVS_KEY_SENSOR_DISAGREEMENT "sensor_disagree"
#define NVS_KEY_ATMOSPHERIC_PRESSURE "atm_pressure"

// Display setting keys
#define NVS_KEY_BRIGHTNESS          "brightness"
#define NVS_KEY_CONTRAST            "contrast"
#define NVS_KEY_AUTO_BRIGHTNESS     "auto_bright"

// System setting keys
#define NVS_KEY_SLEEP_TIMEOUT       "sleep_timeout"

// O2 calibration validity keys
#define NVS_KEY_O2_CAL_VALID        "o2_cal_valid"   // Sensor 1 calibration validity
#define NVS_KEY_O2_CAL_VALID_S2     "o2_cal_val_s2" // Sensor 2 calibration validity

// Date/time keys
#define NVS_KEY_DATETIME            "datetime"

// Duplicate removed - already defined above as SYSTEM_DEFAULT_SLEEP_TIMEOUT_S

#ifdef __cplusplus
extern "C" {
#endif

/**
 * @brief Initialize configuration system and NVS storage
 * @return ESP_OK on success, error code otherwise
 */
esp_err_t app_config_init(void);

/**
 * @brief Load application configuration from NVS
 * @param config Pointer to configuration structure to fill
 * @return ESP_OK on success, error code otherwise
 */
esp_err_t app_config_load(app_config_t *config);

/**
 * @brief Save application configuration to NVS
 * @param config Pointer to configuration structure to save
 * @return ESP_OK on success, error code otherwise
 */
esp_err_t app_config_save(const app_config_t *config);

/**
 * @brief Get default configuration values
 * @param config Pointer to configuration structure to fill with defaults
 */
void app_config_get_defaults(app_config_t *config);

/**
 * @brief Get pointer to current configuration (loads once, cached)
 * @return Pointer to current configuration structure
 */
const app_config_t* app_config_get_current(void);

#ifdef __cplusplus
}
#endif

#endif // APP_CONFIG_H

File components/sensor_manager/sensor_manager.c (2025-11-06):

/**
 * @file sensor_manager.c
 * @brief Sensor manager implementation using ADS1115 for O2 sensor readings
 */

#include "sdkconfig.h"
#include "sensor_manager.h"
// Using internal ADC only - no external sensor managers needed
#include "app_config.h"
#include "esp_log.h"
#include "freertos/FreeRTOS.h"
#include "freertos/task.h"
#include <math.h>
#include "esp_adc/adc_oneshot.h"
#include "esp_adc/adc_cali.h"
#include "esp_adc/adc_cali_scheme.h"
#include "driver/gpio.h"

static const char *TAG = "SENSOR_MGR";
#define LOG_LOCAL_LEVEL ESP_LOG_DEBUG

// Constants & definitions for robust filtering system
#define FILTER_SAMPLE_RATE_HZ           20.0f       // Nominal sample rate
#define FILTER_MEDIAN_WINDOW_SIZE       5           // Median-of-5 filter
#define FILTER_DEFAULT_TAU_SEC          5.0f        // EMA time constant (seconds)
#define FILTER_DEFAULT_S_UP_BAR_S       0.083f      // Default rising PPO2 rate limit (bar/s)
#define FILTER_DEFAULT_S_DOWN_BAR_S     0.05f       // Default falling PPO2 rate limit (bar/s)
// Alarm thresholds removed - handled by warning_manager component

static bool s_initialized = false;
static sensor_data_t s_current_data = {0};
static uint32_t s_read_count = 0;
static uint16_t battery_read_count = 0;
// No pressure sensor data needed - using fixed atmospheric pressure

// Single sensor mode detection

#define SENSOR_DISABLED_THRESHOLD_MV    6    // ADC reading < 6mV indicates disabled channel
static bool s_single_sensor_mode = false;      // true if only one sensor channel is active
static int s_active_sensor_id = -1;            // 0 or 1 for active sensor, -1 if dual mode


// Safety constants
#define MAX_DATA_AGE_MS         5000    // Maximum age for sensor data (5 seconds)
#define MAX_CONSECUTIVE_FAILURES 10     // Maximum consecutive failures before critical error
#define FAIL_SAFE_FO2           0.16    // Conservative fail-safe FO2 (16% instead of 21%)
#define MIN_CALIBRATION_GAS_O2  0.18    // Minimum O2 fraction for calibration gas (18%)
#define MAX_CALIBRATION_GAS_O2  1.0     // Maximum O2 fraction for calibration gas (100%)

// Recovery thresholds
#define RECOVERY_ATTEMPT_THRESHOLD  5   // Start recovery attempts after 5 consecutive failures
#define SENSOR_REINIT_THRESHOLD    15   // Re-initialize sensors after 15 consecutive failures  
#define SYSTEM_RESET_THRESHOLD     30   // System reset after 30 consecutive failures

// Failure tracking
static uint32_t s_consecutive_o2_failures = 0;
// s_consecutive_pressure_failures removed - no pressure sensor used

// Recovery state tracking
static uint32_t s_last_recovery_attempt_time = 0;
static uint32_t s_sensor_reinit_count = 0;
static bool s_system_in_recovery = false;



#define SENSOR_ADC_ATTEN       ADC_ATTEN_DB_0
#define BATTERY_ADC_ATTEN      ADC_ATTEN_DB_2_5  // 11dB attenuation for battery voltage
#define ADC_WIDTH               ADC_BITWIDTH_12   // 12-bit resolution

// ADC channels for sensors (ESP32-C3 specific)
// GPIO9 -> ADC1_CHANNEL_9 is not valid on ESP32-C3, use GPIO0-4
// Let's use GPIO0 and GPIO1 instead which map to ADC1_CHANNEL_0 and ADC1_CHANNEL_1
#define GPIO_SENSOR1_ADC        GPIO_NUM_0  // O2 Sensor #1 ADC input (ADC1_CHANNEL_0)
#define GPIO_SENSOR2_ADC        GPIO_NUM_1  // O2 Sensor #2 ADC input (ADC1_CHANNEL_1)
#define GPIO_BATTERY_ADC        GPIO_NUM_3  // Battery voltage ADC input (ADC1_CHANNEL_2)
#define SENSOR1_ADC_CHANNEL     ADC_CHANNEL_0   // GPIO0 for ESP32-C3
#define SENSOR2_ADC_CHANNEL     ADC_CHANNEL_1   // GPIO1 for ESP32-C3
#define BATTERY_ADC_CHANNEL     ADC_CHANNEL_3   // GPIO2 for ESP32-C3 (battery voltage divider)
#define ADC_S1_OFFSET_MV      0     // Calibration offset for sensor 1 (mV)
#define ADC_S2_OFFSET_MV      0     // Calibration offset for sensor 2 (
#define DISCARD_SAMPLES   8     // throw away first N samples after a channel switch
#define AVERAGE_SAMPLES   24    // increased from 12 to 24 for better stability (reduces ±1mV noise)



// Internal ADC handles
static adc_oneshot_unit_handle_t s_adc1_handle = NULL;
static adc_cali_handle_t s_adc1_cali_sensor1_handle = NULL;
static adc_cali_handle_t s_adc1_cali_sensor2_handle = NULL;
static adc_cali_handle_t s_adc1_cali_battery_handle = NULL;
static bool s_adc_calibrated_sensor1 = false;
static bool s_adc_calibrated_sensor2 = false;
static bool s_adc_calibrated_battery = false;

// Legacy calibration data - no longer used (kept for compatibility)
// All calibration now handled by multipoint calibration system


// ADC calibration helper functions
static bool adc_calibration_init(adc_unit_t unit, adc_channel_t channel, adc_atten_t atten, adc_cali_handle_t *out_handle);
static void adc_calibration_deinit(adc_cali_handle_t handle);


// Robust filter function implementations

/**
 * @brief Compute per-sample clamp magnitudes for two sensors from their measured k and physical slew limits
 */

 


// Helper function to check data staleness
static bool is_data_stale(uint32_t current_time)
{
    return (current_time - s_current_data.timestamp_ms) > MAX_DATA_AGE_MS;
}

// Recovery functions
static esp_err_t attempt_sensor_recovery(void);
static esp_err_t reinitialize_sensors(void);
static void trigger_system_reset(void);
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

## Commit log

2025-09-15 different attens for battery and sensor adc channels
2025-09-16 single sensor mode detection
2025-09-18 voltage divider ratio update
2025-09-19 Major issue with 2 point calibration correction. Some stack overflow during logging corrected
    [main.c, sensor_manager.c]
2025-09-19 add circuit.png
2025-09-21 power friom battery alligments
2025-09-22 get rid of float point operations in sensor management. Simplify filtering
2025-09-22 battery bias adc channel corrected
    [sensor_manager.c]
2025-09-23 Power consumption optimization
2025-10-08 deep sleep if battery < 2.8
2025-10-13 adjustments to CR2 battery
2025-10-21 new CR2 battery start up issues
    [display_manager.c, main.c, sensor_manager.c]
2025-11-01 KiCad PCB
    [bom.csv, designators.csv, esp_ppo_v2.kicad_pcb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]
2025-11-06 Button issues clean-up
2025-11-06 switch from mv to ADC readings in ppo calc for precision
2025-11-06 filter adjustments
2025-11-06 battery cut off

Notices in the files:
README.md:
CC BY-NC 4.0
